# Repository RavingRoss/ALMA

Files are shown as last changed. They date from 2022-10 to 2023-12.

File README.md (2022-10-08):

# ALMA
The Advanced LASER Mining Array (ALMA) is a theoretical model of a Fiber LASER capable of mining ice water in space. This is being designed in the Engineering Physics Propulsion Lab at Embry Riddle Aeronautical University in Daytona Beach, FL. 

 A few examples that ALMA could mine are ice on the moon, C-type asteroids, comets, and other planetary bodies. There will be a downsized model of the LASER to help derive constants for the equations in the simulations and also for a proof-of-design. We are hoping the outcome will prove that you can use a FBL to mine ice water efficiently, with low energy and high output, in the vacuum of space. 
 
 The simulations will be based on the environment, meaning we can test the FBL in a vacuum, or on Venus. Decisions are still being made on what language and program to use for the simulations.

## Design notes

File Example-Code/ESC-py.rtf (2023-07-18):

# This program will let you test your ESC and brushless motor.

# Make sure your battery is not connected if you are going to calibrate it at first.

# Since you are testing your motor, I hope you don't have your propeller attached to it otherwise you are in trouble my friend...?

# This program is made by AGT @instructable.com. DO NOT REPUBLISH THIS PROGRAM... actually the program itself is harmful pssst Its not, its safe.

import os #importing os library so as to communicate with the system
import time #importing time library to make Rpi wait because its too impatient
os.system ("sudo pigpiod") #Launching GPIO library
time.sleep(1) # As i said it is too impatient and so if this delay is removed you will get an error
import pigpio #importing GPIO library

ESC=4 #Connect the ESC in this GPIO pin

pi = pigpio.pi();
pi.set_servo_pulsewidth(ESC, 0)

max_value = 2000 #change this if your ESC's max value is different or leave it be
min_value = 700 #change this if your ESC's min value is different or leave it be
print "For first time launch, select calibrate"
print "Type the exact word for the function you want"
print "calibrate OR manual OR control OR arm OR stop"

def manual_drive(): #You will use this function to program your ESC if required
print "You have selected manual option so give a value between 0 and you max value"
while True:
inp = raw_input()
if inp == "stop":
stop()
break
elif inp == "control":
control()
break
elif inp == "arm":
arm()
break
else:
pi.set_servo_pulsewidth(ESC,inp)

def calibrate(): #This is the auto calibration procedure of a normal ESC
pi.set_servo_pulsewidth(ESC, 0)
print("Disconnect the battery and press Enter")
inp = raw_input()
if inp == '':
pi.set_servo_pulsewidth(ESC, max_value)
print("Connect the battery NOW.. you will here two beeps, then wait for a gradual falling tone then press Enter")
inp = raw_input()
if inp == '':
pi.set_servo_pulsewidth(ESC, min_value)
print "Wierd eh! Special tone"
time.sleep(7)
print "Wait for it ...."
time.sleep (5)
print "Im working on it, DONT WORRY JUST WAIT....."
pi.set_servo_pulsewidth(ESC, 0)
time.sleep(2)
print "Arming ESC now..."
pi.set_servo_pulsewidth(ESC, min_value)
time.sleep(1)
print "See.... uhhhhh"
control() # You can change this to any other function you want

def control():
print "I'm Starting the motor, I hope its calibrated and armed, if not restart by giving 'x'"
time.sleep(1)
speed = 1500 # change your speed if you want to.... it should be between 700 - 2000
print "Controls - a to decrease speed & d to increase speed OR q to decrease a lot of speed & e to increase a lot of speed"
while True:
pi.set_servo_pulsewidth(ESC, speed)
inp = raw_input()

if inp == "q":
speed -= 100 # decrementing the speed like hell
print "speed = %d" % speed
elif inp == "e":
speed += 100 # incrementing the speed like hell
print "speed = %d" % speed
elif inp == "d":
speed += 10 # incrementing the speed
print "speed = %d" % speed
elif inp == "a":
speed -= 10 # decrementing the speed
print "speed = %d" % speed
elif inp == "stop":
stop() #going for the stop function
break
elif inp == "manual":
manual_drive()
break
elif inp == "arm":
arm()
break
else:
print "WHAT DID I SAID!! Press a,q,d or e"

def arm(): #This is the arming procedure of an ESC
print "Connect the battery and press Enter"
inp = raw_input()
if inp == '':
pi.set_servo_pulsewidth(ESC, 0)
time.sleep(1)
pi.set_servo_pulsewidth(ESC, max_value)
time.sleep(1)
pi.set_servo_pulsewidth(ESC, min_value)
time.sleep(1)
control()

def stop(): #This will stop every action your Pi is performing for ESC ofcourse.
pi.set_servo_pulsewidth(ESC, 0)
pi.stop()

#This is the start of the program actually, to start the function it needs to be initialized before calling... stupid python.

inp = raw_input()
if inp == "manual":
manual_drive()
elif inp == "calibrate":
calibrate()
elif inp == "arm":
arm()
elif inp == "control":
control()
elif inp == "stop":
stop()
else :
print "Thank You for not following the things I'm saying... now you gotta restart the program STUPID!!"

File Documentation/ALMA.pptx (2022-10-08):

## Advanced Laser mining array (alma)

Fiber Laser (FBL) using Ytterbium (Yb) doped fiber cable

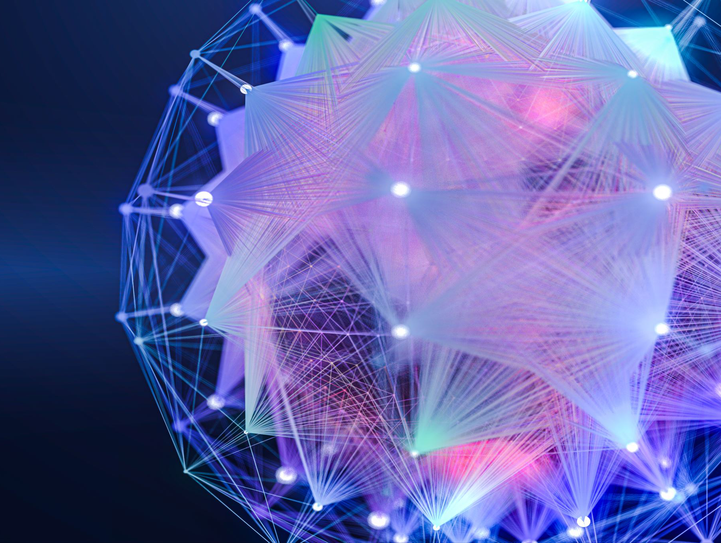
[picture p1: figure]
Purple patterned lights

Jacob R. Romeo

## Purpose and Plan for ALMA

- Main purpose will be to prove that the FBL could mine ice on the moon and NEOs.
- This involves making a downsized, low powered model to confirm the design.
- After, run Mathematical Models to know what we need to make the scaled version.
- Possibly getting funding for an up-scaled version.

## Design

- The Fiber Laser is pumped with a diode (976nm).
- The diode is coupled to the fiber cable.
- The doped, Yb core of the fiber cable uses stimulated emission to amplify the output.

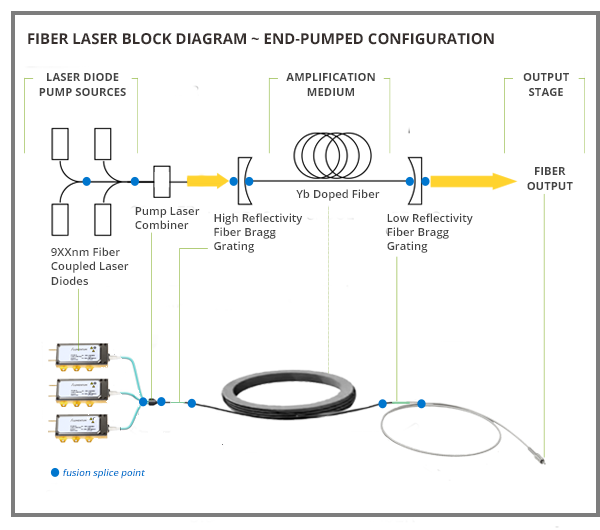
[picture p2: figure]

## Drilling Technique

- Different techniques are used for different applications.
- For our purposes, we want a large area with high energy impulses.
- Possibly using more than one output fiber to get a larger area of effect.

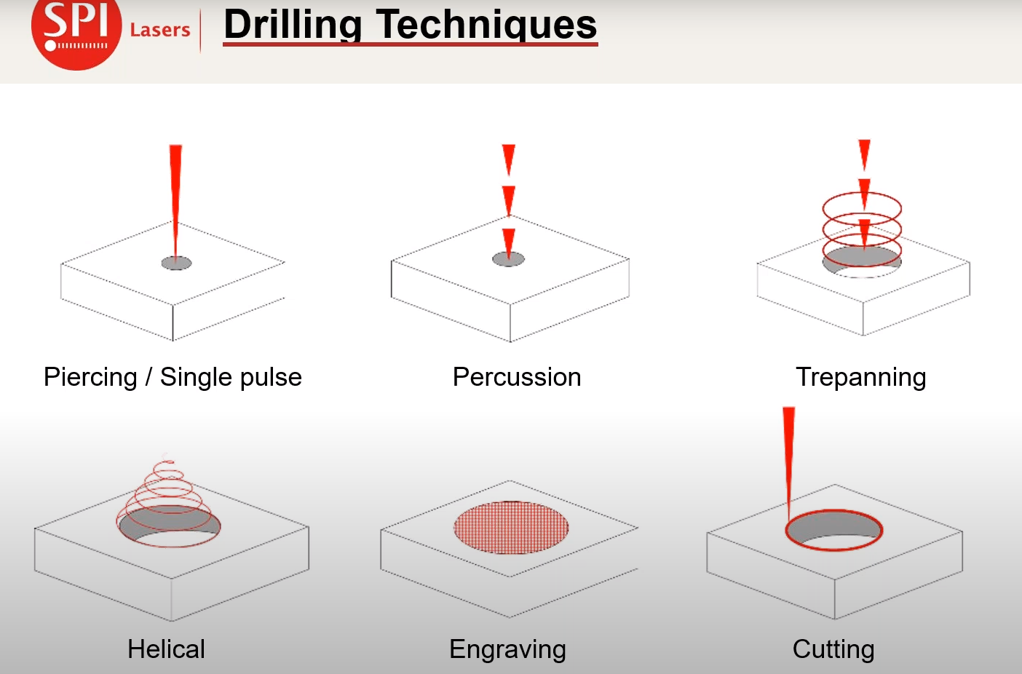
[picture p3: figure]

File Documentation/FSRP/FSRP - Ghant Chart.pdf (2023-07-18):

TASKS | M 1 | M 2 | M 3 | M 4 | M 5 | M 6 | M 7 | M 8 | M 9 | M 10 | M 11 | M 12

Confirm design specifications for 976nm BTF Diode, control board, Yb doped fiber optic, mirrors, and FBG's, then order components for the FBL and appratus

Get the absorption spectrum of water ice using a spectrometer and thin sheet of ice

Assemble the apparatus with the Yb fiber cable, mirror, and grating and mount the FBL for power testing

If Lasing, test with different grating angles to see which wavelength has best absoprtion effect on the ice to confirm the absorption spectrum

Start simulations in python to calculate power needed for high powered FBL and simulate this in Ansys

Order neccessary FBG to make a condensed design
Couple the fiber optics instead of a free-space design to condense the apparatus and show a plug-n-play design

Test power with plug-n-play design and confirm absorption spectra Use spectra from experiments in sumlations to more accurately depict effects on water ice in a vacuum environment

Reach out for more opportunities with NASA for future research

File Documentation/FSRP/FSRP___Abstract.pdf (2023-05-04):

## Advanced LASER Mining Array (ALMA)

Principal Investigator: Dr. Vikas Sudesh

Student Team: Jacob Romeo, Joseph DeMartini,

and Paige Loverick

April 2023

## 1 Abstract

ALMA is a fiber-laser (FBL) apparatus that will show a technique to mine water ice in space.

The ALMA will use absorbance to its advantage to melt water ice at low power so that energy

consumption is not an issue in space. Water ice’s absorption coefficient peaks in the near-infrared

range, thus the FBL will have an output ranging from 1060nm-1100nm. The FBL is going to

have a source (coupled diode) of 976nm, which will be of low wattage at 1.2W, being pumped

through the Ytterbium doped fiber cable. This is going to be done by using a variety of fiber

Bragg gratings to polarize the output to a specific wavelength. The purpose of this process is to

experimentally derive the absorption coefficient of water ice by melting it and reading its spectra

from a spectrometer so that the extinction coefficient can be solved. The extinction coefficient is

then used to find the absorbance, solving for the Intensity of the beam. After this is done, python

will be used to numerically solve (using the coefficients found) the equations for the physics inside

the FBL, so that Ansys can simulate a high-powered laser in a space environment. The reason

for doing this is due to costs, thus the ALMA team will be submitting future proposals to NASA

for larger grants in the future. This project is an huge learning curve and amazing experience for

the students working on this, including the assembly of the apparatus, the physics and concepts,

simulations, and working under time constraints.

1

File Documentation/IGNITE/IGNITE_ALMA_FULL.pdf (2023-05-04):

# Proof of Design for the Advanced LASER Mining Array (ALMA)

Principal Investigator: Jacob Romeo Student Team: Joseph DeMartini, Phoebe Fleshman, and Nathan Honderick
Supervisor: Dr. Sergey V. Drakunov

January 28, 2023

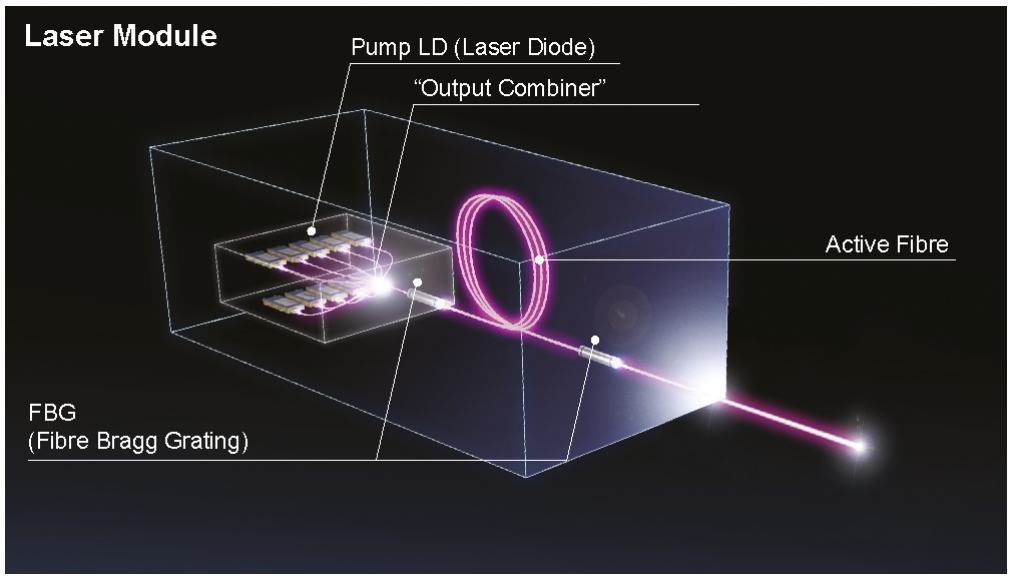
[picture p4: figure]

## Nomenclature

µ = 10⁻⁶

C − T ype = Carbonaceous chondrites

EP P L = Engineering Physics Propulsion Lab

Er = Erbium

F BG = Fiber Grating

F BL = Fiber LASER

K = Kelvin

LASER = Light Amplification by Stimulated Emission of Radiation

nd : Y AG = neodymium-doped:Yttrium Aluminium Garnet

NEO′ | s = Near earth objects

P P E = Personal Protective Equipment

SOP = Standardized Operating Procedure

Tm = Thulium

Y b = Ytterbium

## 1 Abstract

The goal of the ALMA project is to design and create an apparatus to test the ability of a FBL to mine water ice in space. This includes ice on the moon, NEO’s, and asteroids in the asteroid and Kuiper belt (which mainly consist of C-types and comets) [3]. ALMA is a down-sized version of the full lASER, being able to melt smaller chunks of ice. The reason for using a FBL versus a nd:YAG or CO2 gas LASER is to make use of the efficiency and accessibility of the FBL. The FBL is a more cost effective, and energy efficient laser, while also more compact than its counterparts [5]. The simpler design, allows it to be both reliable and maintenance-free during use [1]. Most high powered FBL’s have a recorded 30% - 50% power efficiency, much greater than other options [4]. Because of this the FBL was found to be the best option.
The basic design of a FBL utilizes: coupled diodes, a combiner, a Yb doped fiber cable, FBG (one of higher polarization on the input and another of low polarization on the output), and a FBG to protect the inside of the cable (Fig. 1 ). Due to the fact this project is researching means of mining in space, where the resting temperature is approximately 2.7K, there would be no use for cooling. More likely a means to find ways to shield the FBL from the space environment will need to be developed, because temperatures do not remain consistent once on the surface of the moon and other bodies in space. Because of this, the components will need to be changed based on the FBL based on its environment it is mining.
To complete the project and its goals, there will be a safety plan implemented as follows. The downsized model will have a system of precaution, including PPE, a safe and isolated environment for testing, and documentation with information disclosing safety measures.

## 2 Background

After Albert Einstein discovered the math that describes lasers in 1917, work stagnated until the 1950s with the first successful design in 1960. It wasn’t until 1963 when Elias Snitzer demonstrated a FBL [6]. This work was evolved to create lasers that are used to cut precious metals or in communication systems. In recent years the most common point of discussion is for mining, as it is the most rewarding possibility for FBLs to be used.
The function of a FBL works by using a diode coupled to a doped fiber optic cable, with amplification by stimulation. Some dopants for the amplification process are the elements Yb, Er, and Tm [6]. This process is called population inversion, defined as the redistribution of energy levels by collisional excitation of the electrons in the atom [7]. When electrons collide with a photon, from the pump source, it becomes energized and jumps to a higher energy level (Fig. 3 ). This process can be mathematically described by the elementary equation: E2 − E1 = ∆E = hf, where h is Plank’s Constant and f is the frequency of light. Once the electron goes back to the ground state and re-emits the photon, it gets reflected from the high reflective FBG, thus exciting more electrons and emitting more photons. From this quantum phenomena, a single photon can start a domino effect and amplify the input significantly and quickly.
The cladding of the fiber cable, surrounding the doped core, allows the light to have total internal reflection (Fig. 2 ) allowing minimal energy loss and scattering. This effect comes from Snell’s law: sin(θc) =

nclad
ncore

, where n is the refractive index. For this to work and there to be total internal reflection: nclad < ncore. There can be some scattering loss due to bending of the cable, which can be calculated and accounted for. The FBG on each end of the fiber filter the photons so that it can be reflected and energized to the correct wavelength (λ). For the current setup, ALMA will have λ ≈ 1070nm. The input grating has a larger reflectivity, thus no light can re-enter the diode and it is reflected to be amplified. Once the photon has reached the max wavelength (1070 nm), it is transmitted through the low reflectivity FBG.

## 3 Methodology

ALMA will be a down-scaled version of the theoretical FBL at about 1.2 Watts of peak output power, giving a pulse energy of .24µJ at a pulse width of 20µs. There will be a control board with the diode soldered on, giving us the ability to change the pulse-width parameters and input/output power. Within the lab, we plan on building a test cell made from 80/20 linear rails, the laser will be contained in the cell. Around this test cell will be a polarization screen, explained in section Safety Precautions. The apparatus will show mining techniques and collect spectra data from ice. This spectra data will be used when compiling the simulations, deriving the power needed to complete this task in different environments. The goal is to see how applicable this idea is with current technology. If not at all, the simulations can tell us why and what we need for it to come to fruition. It is also a lot more inconvenient and expensive to do tests with a higher powered FBL. Thus with the smaller version, ALMA is still able to experimentally derive the necessary processes that the simulations will be sourced from.
Currently, there is no precise value for the absorbance of ice, which is the lowest power requirement to melt ice. The basic definition of the absorbance, stated as the Beer-Lambert Law: An absorbance of 0 corresponds to a transmittance of 100% and an absorbance of 1 corresponds to 10% transmittance [11]. This comes from: A = αcl and α =

4πk
λ

, where A is absorbance, α is absorption coefficient, c is molar concentration, l is optical path length, k is extinction coefficient, and λ is wavelength. The absorption coefficient is defined: How far into a material light of a particular wavelength can penetrate before it is absorbed [12] and the extinction coefficient: How efficiently light is absorbed or reflected from a material [12]. Because of this, we will need to experimentally derive k and α to solve for A. This is important because without these values λ for the system is essentially an educated guess, which is what we are currently doing. Thus in the future, ALMA will need to incorporate different FBG, testing with different λs to derive the best absorbance value for the system.
Some other examples of why testing with different FBG will help ALMA’s progression include power output, beam quality, mining techniques, etc. Completing any of these experimentally will help the theoretical process and also make it more accurate for our goals.

| TASKS | START DATE | COMPLETION DATE
1 | IGNITE grant is rewarded | 07/2023 | -
2 | Order components for FBL and apparatus | 07/2023 | 08/2023
3 | Make apparatus to mount FBL | 08/2023 | 08/2023
4 | Start testing FBL | 08/2023 | 08/2023
5 | Research Symposium | Fall TBA | Fall TBA
6 | Collect spectra and mining data | 09/2023 | 11/2023
7 | Testing w/ more FBG(if enough $) | 11/2023 | 01/2024
8 | Repeat 6. with other FBG | 01/2024 | 02/2024
9 | Discovery Day | Spring TBA | Spring TBA
10 | Compile sim with spectra data | 03/2024 | 05/2024
11 | Publish research | 05/2024 | 05/2024
12 | Reach out for more opportunities | 05/2024 | 07/2024

## 4 Safety Precautions

The EPPL in room 123.1 of the COAS is a very secure environment to preform experiments. Storing ALL of ALMA’s equipment, including PPE, the apparatus, and experimental tools. There is also a test cage in which all of the experiments will be preformed along with a protective screen that blocks all light emission. The screen is present so that if light gets scattered or reflected it will not injure any researchers or damage sensitive equipment. The researchers working on ALMA will be wearing PPE at all times, including polarized goggles and latex gloves. In the test cage, there will be designated spot for NO crossing, where the beam would be active along with a sign outside the lab door signaling the use of a LASER. Money will also be allocated to buying a downsized test cell with the ability to install polarization features, in the case the screen cannot be purchased.

### 4.1 Storage’s SOP

Money for the FBL equipment will be allocated for secure, pelican crates for the equipment. It will be stored in a room behind a locked door, and will only be available to the PI once stored. Only 3 research interns and the supervisor have access to this door inside the lab once locked. The PPE will also be stored in pelican crates inside the test cage along with the equipment. The PPE includes polarized goggles, grounding cables, and protective gloves. Along with this, there will be NO jewelry of any kind when handling/experimenting with equipment.

### 4.2 Experiment’s SOP

The experiments will always be conducted inside the test cage, behind the locked door, inside the lab. There will be warning lights when the FBL is active and will be warning signs on the locked lab door and test cage at all times. Inside the test cage, there will be warning tape, at all times, where the beam would cross while active. The FBL will also have a switch to turn power on/off and a shutter on the output lens to block any light coming out of the FBL, on or off. Stated above, the test cage will have polarization tint so that if the beam gets reflected towards the cage, it will not be transmitted through the cage.

## 5 Significance

Space mining is one of the ”Big Talks” in fields of science and business alike. Once pioneered and efficient, mining in space will rid the need for ripping earth of its materials. If we continue to mine earth, we will eventually run out of resources within the millennia. Mining in space also gives humans the ability to complete space travel easier and generate new processes of wealth. This project introduces the concept of using a FBL to mine in space. From this project, the aerospace industry will have a new, optimized process of extracting water ice from space, allowing companies to make fuel from hydrogen or steam and have an oxygen supply. ALMA will also exponentially increase this team’s knowledge in areas of lab competency and safety, experimental processes of LASERs, physics of LASERs, and mathematics. Feeding this team the knowledge we need to be successful in each of our fields.

## 6 Communication Plans

The findings of ALMA will first and foremost be shared with Embry Riddle Aeronautical University. An accumulation of the findings, data, and simulations will also be shared to multiple journals in hopes of publication regarding the project. We will also apply for more grants and reach out to companies in hopes of partnership to further the research of ALMA.

## 7 Adequacy of Resources

All experiments will be conducted in the EPPL, room 123.1, in the College of Arts and Sciences at Embry Riddle Aeronautical University. There is sufficient space to include all measures for storage and operation, along with adequate tools and additional resources. The EPPL comes with 10 3D printers, including a 0.6 cubic meter printer, that are available for the ALMA team to use when needed. Dr. Sudesh, who has more than 20 years of experience in conducting experiments with FBLs, solid state LASERs, and optics, will be a mentor for the team. His knowledge and industry connections will help in many ways throughout this project. Also Dr. Drakunov, who is the founder of the lab, will provide an excellent source of knowledge when applying the results to the simulations.

## 8 Appendix


Figure 1: FBL design setup for amplification [7]

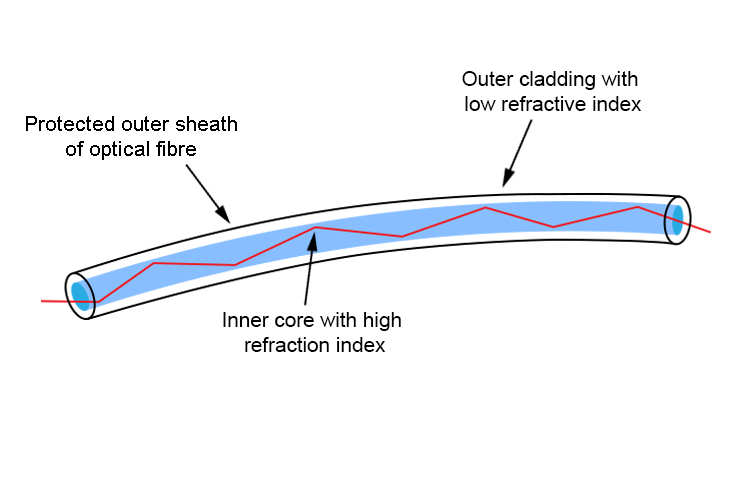
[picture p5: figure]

Figure 2: Example of total internal reflection in cable [8]

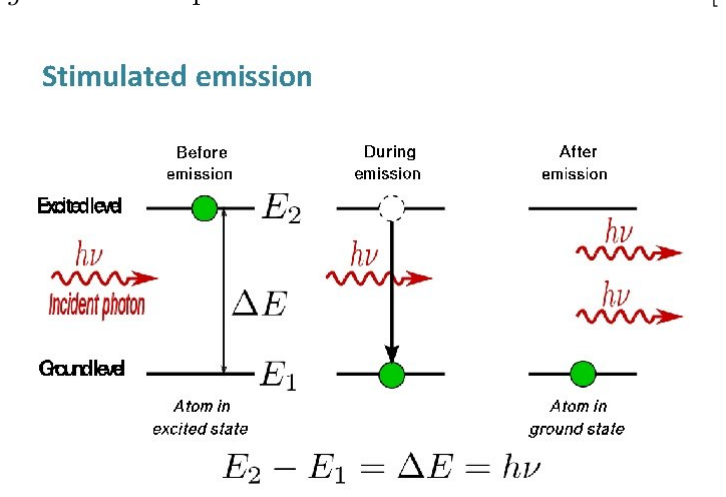
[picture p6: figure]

Figure 3: Population inversion cartoon example [9]

## 9 References

[1] Butterfly, B. (2022, March 15). Fiber Laser: 7 advantages and differences. FindLight Blog. Retrieved

October 3, 2022, from https://www.findlight.net/blog/2022/03/15/7-advantages-of-fiber-laser/

[2] Laserax. (2022, February 7). CO2 vs. Fiber Laser - which one should you buy? Laserax. Retrieved

October 3, 2022, from https://www.laserax.com/blog/co2-vs-fiber-lasers

[3] Lovett, R. A. (2021, January 8). From the vault: Icy asteroids? Cosmos. Retrieved October 3, 2022,

from https://cosmosmagazine.com/space/icy-asteroids/

[4] Photonic frontiers: High-efficiency optical pumping: ’going green ... (n.d.). Retrieved October 3, 2022,

from https://www.laserfocusworld.com/lasers-sources/article/16547048/photonic-frontiers-highefficiency-optical-

pumping-going-green-cranks-up-the-laser-power

[5] Laserax. (2021, September 23). Fiber Lasers: Everything You Need To Know. Laserax. Retrieved

October 3, 2022, from https://www.laserax.com/blog/fiber-laser#:˜:

text=1963%20%E2%80%93%20The%20first%20fiber%20laser,is%20demonstrated%20

(Elias%20Snitzer).

[6] What are rare-earth doped fibers? Fosco Connect. (n.d.). Retrieved October 3, 2022, from

https://www.fiberoptics4sale.com/blogs/archive-posts/95044294-what-are-rare-earth-doped-fibers

[7] Fiber Laser Basics and design principles. Fiber Laser Basics and Design Principles (with VIDEOS).

(n.d.). Retrieved October 3, 2022, from https://www.laserlabsource.com/Solid-State-Lasers/Solid-State-

Lasers/fiber-laser-basics-and-design-principles

[8] Total Internal Reflection. Total internal reflection experiments and optical fibres. (n.d.). Retrieved Oc-

tober 3, 2022, from https://mammothmemory.net/physics/refraction/total-internal-reflection-experiments-

and-optical-fibres/total-internal-reflection-experiments-and-optical-fibres.html

[9] Laser light amplification by stimulated emission of radiation. SlideToDoc.com.(n.d.).Retrieved Octo-

ber 3, 2022, from https://slidetodoc.com/laser-light-amplification-by-stimulated-emission-of-radiation-5/

[10] Sharp, T., amp; Urrutia, D. E. (2022, February 28). What is the temperature on the Moon?

Space.com. Retrieved January 31, 2023, from https://www.space.com/18175-moon-temperature.html

[11] Granite, S. by. (2023, February 14). Beer Lambert law: Transmittance amp; Absorbance. Edinburgh

Instruments. Retrieved February 24, 2023, from https://www.edinst.com/blog/the-beer-lambert-law/

[12] Absorption coefficient. PVEducation. (n.d.). Retrieved February 24, 2023, from

https://www.pveducation.org/pvcdrom/pn-junctions/absorption-coefficient

## 10 Student Group Resume

Jacob Romeo: A second semester junior in Astronomy and Astrophysics with research experience in

applied and theoretical physics, astronomy, electrical and software engineering, and control theory. Over 4

years of experience with electronics (PCB development) and coding in python. Experienced using Fusion360

CAD software, C++ and java, and development with raspberry-Pi’s and Arduino’s.

Phoebe Fleshman: A second semester junior in Engineering Physics with a focus on spacecraft systems.

Roughly 2 years of technical experience designing and building robots. Along with roughly 2 years of budget

creation and management . Experienced using Autodesk Inventor Pro, MatLab, and CNC mills.

Joseph DeMartini: A third year Engineering Physics student with professional experience in software

development and simulation. 5+ years of experience in Java, C#, and Unity3D development with an

understanding of advanced software development practices. Experience in applying numerical methods and

modern physics concepts to create high fidelity 3D physics simulations in optics, orbital mechanics, and

electromagnetism.

Nathan Honderick: A second semester freshman in Aerospace Engineering, specializing in Astronau-

tics. Experienced using Matlab, Onshape, Inventor, and Catia CAD software. Currently working on a

CubeSat, a laser mining array, a hybrid rocket engine, and developing a patent for an eco-friendly product

crafted from up-cycled beach plastic.

## 11 Detailed Budget

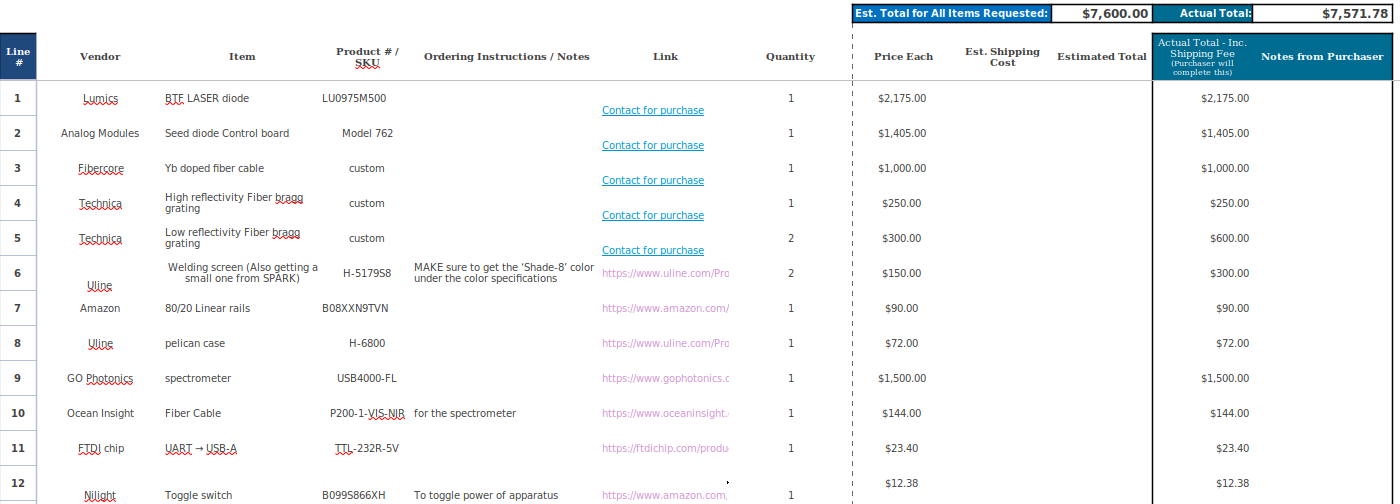
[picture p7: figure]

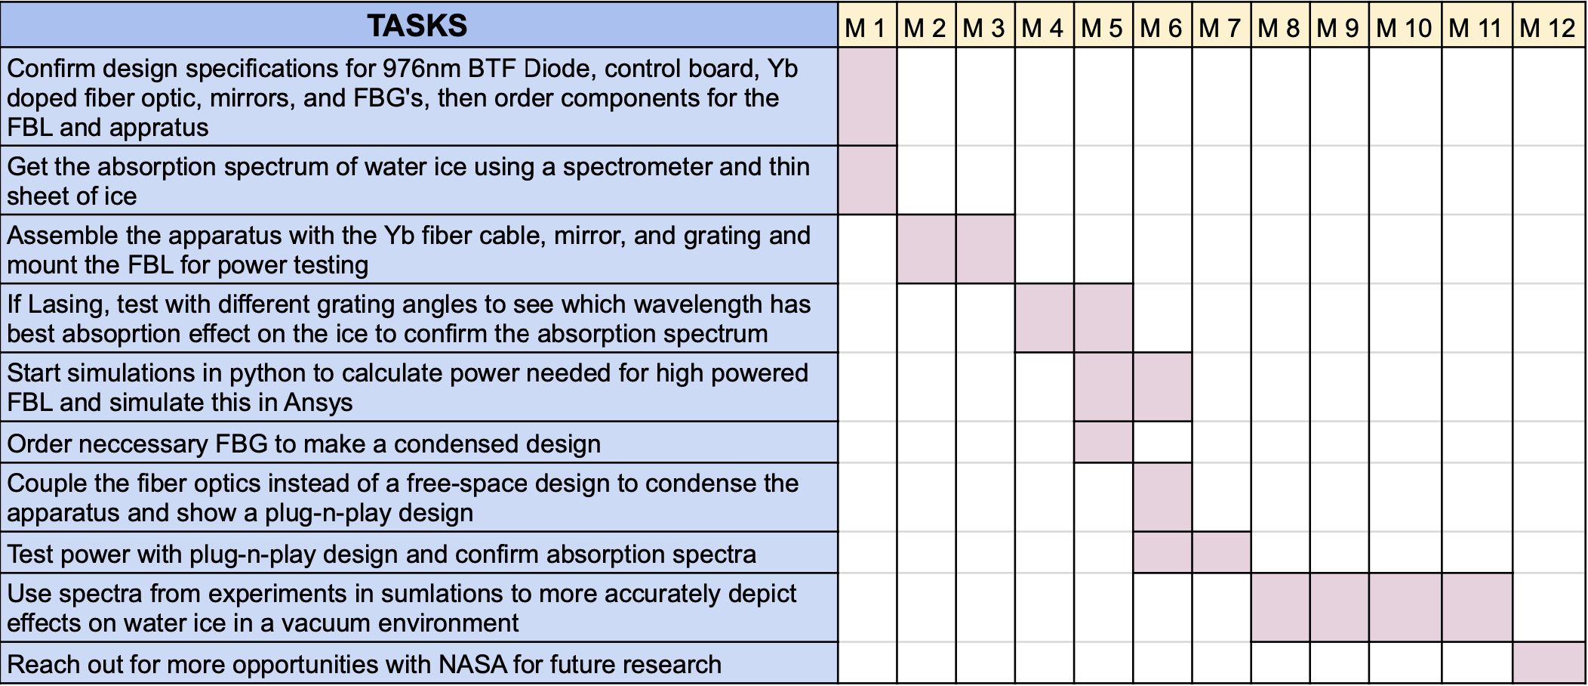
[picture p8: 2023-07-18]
Documentation/FSRP/Screenshot 2023-05-22 at 9.54.50 AM.png

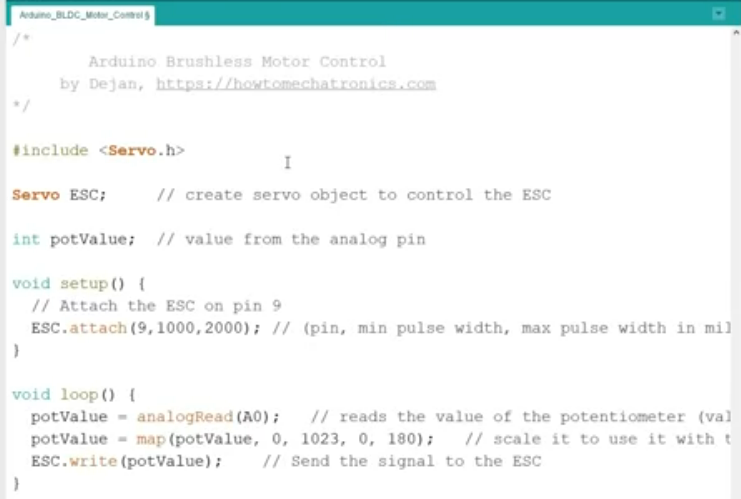
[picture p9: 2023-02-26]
Documentation/BLDC-ESC-Control.png

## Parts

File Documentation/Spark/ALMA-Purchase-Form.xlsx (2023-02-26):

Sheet: Instructions
Please click here to review the OUR Purchasing Guidelines prior to completing this form.
Purchase Request Form: • Used to request the purchase of all supplies/materials as needed. • Group all items by vendor. • Purchase from Amazon whenever possible. • Include any special instructions/details. • Include additional info for electronic and hazardous items in tabs below (required). • Provide direct links to exact item requested. • Provide shipping estimates. • Provide item ID #. • Provide lab/building address for shipment in email.
Electronic, computer & software purchases: • IT APPROVAL REQUIRED. • Provide a brief description of what the item(s) will be used for on the "Electronic Items" tab below. • OUR will obtain IT approval on your behalf. • Includes but not limited to: external hard drives, motherboards, Raspberry Pi, cameras, laptops, printers, etc.
Hazardous, chemical & gas purchases: • EH&S Review and Acceptance REQUIRED before purchasing. • You and your Faculty Mentor are responsible for obtaining a review and acceptance of your comprehensive SOP by the University’s Environmental Health & Safety Office prior to submitting Purchase Requests for hazardous, chemical, or gas purchases. • Complete the “Chemical & Compressed Gas Purchase” form linked in the "Hazardous & Chemicals" Tab below. • Once review is completed by EH&S, submit the acceptance with your Purchase Request Form to the OUR Business Manager and complete "Hazardous & Chemicals" Tab below.
Single Purchases $3,000 or more: • Due to the high expense, a Purchase Requisition must be submitted to purchase the item. • You must provide to the Business Manager along with your completed Purchase Request Form an itemized quote from the vendor and a copy of the vendor’s W-9 Form. • Single Purchases $5,000 or more are considered Capital Requests and require additional paperwork and approvals. • Please plan to purchase items of this nature as soon as possible as it often takes longer to process and receive the item.

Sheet: Purchase Request
 | Student Name: | Jacob R. Romeo |  | Project Title: | Advanced LASER Mining Array |  |  | Type of Funding (Spark, Ignite, Student Internal, SURF): |  | Spark
 | SHIP TO: (Faculty / Lab Director Name) | Engineering Physics Propulsion lab |  | Lab / Building Name and Building # : | COAS |  |  |  | Room # : | 123.1
 | Group items by vendor and include all relevant information needed for ordering. Email a copy of this to Liz Payne: paynee6@erau.edu.
 | ***Additional info MUST be provided on tabs below for ALL electronic, computer and hazardous/chemical items.***
 |  |  |  |  |  |  | Est. Total for All Items Requested: |  | $998.28 | Actual Total: | $998.28
Line # | Vendor | Item | Product # / SKU | Ordering Instructions / Notes | Link | Quantity | Price Each | Est. Shipping Cost | Estimated Total | Actual Total - Inc. Shipping Fee (Purchaser will complete this) | Notes from Purchaser
1 | Thorlabs | Round Wedge Prism 2* | PS810-C |  | https://www.thorlabs.com/thorproduct.cfm?partnumber=PS810-C | 2 | $54.16 |  | $108.32 | $108.32
2 | Thorlabs | Round Wedge Prism 4* | PS811-C |  | https://www.thorlabs.com/thorproduct.cfm?partnumber=PS811-C | 2 | $54.16 |  | $108.32 | $108.32
3 | Thorlabs | Round Wedge Prism 6* | PS812-C |  | https://www.thorlabs.com/thorproduct.cfm?partnumber=PS812-C | 2 | $54.16 |  | $108.32 | $108.32
4 | Flash Hobby | BLDC motors | B07545RQ62 |  | https://www.amazon.com/DYS-2200KV-Brushless-Multirotor-Quadcopter/dp/B07545RQ62 | 4 | $16.58 |  | $66.32 | $66.32
5 | Supulse | Electric Speed Controller | B071GRSFBD |  | https://www.amazon.com/RC-Brushless-Electric-Controller-bullet/dp/B071GRSFBD | 4 | $16.99 |  | $67.96 | $67.96
6 | Overture | 3D filament | N/A |  | https://www.amazon.com/OVERTURE-Filament-Printer-Dimensional-Accuracy/dp/B089S2QDHD | 1 | $20.00 |  | $20.00 | $20.00
7 | Zeee | 2 3s LiPo Batt | B07Y67MPKW |  | https://www.amazon.com/Zeee-Graphene-Quadcopter-Helicopter-Airplane/dp/B07Y67MPKW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 | 2 | $45.99 |  | $91.98 | $91.98
8 | Supulse | 4pcs LiPo Battery Case | FBB125x4-02 |  | https://www.amazon.com/Battery-Fireproof-Explosion-Proof-Storage/dp/B078Y723Z3?hvadid=459723993320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 | 1 | $14.99 |  | $14.99 | $14.99
9 | Civil Laser | 680nm 10mW Red laser module | Product 64/83:No Part number | HAVE to specify DOT shape, not line or crosshair | https://www.civillaser.com/index.php?main_page=product_info&products_id=1276 | 1 | $94.00 |  | $94.00 | $94.00
10 | AtomStack | LASER Protective Eye glasses | AtomOD5 |  | https://www.atomstack.net/products/atomstack-od5-laser-protective-glasses?currency=USD&variant=41033735405749 | 4 | $39.99 |  | $159.96 | $159.96
11 | Uline | Welding Screen | H-5179S8 | MAKE sure to get the ‘Shade-8’ color under the color specifications | https://www.uline.com/Product/Detail/H-5179S8/Welding/Welding-Screen-6-x-8-Shade-8 | 1 | $150.00 |  | $150.00 | $150.00
12 | Grainger | Safety sign | 451R27 |  | https://www.grainger.com/product/451R27?gucid=N:N:PS:Paid:GGL:CSM-2295:4P7A1P:20501231&gclsrc=aw.ds | 1 | $8.11 |  | $8.11 | $8.11
13 |  |  |  |  |  |  |  |  |  | $0.00
14 |  |  |  |  |  |  |  |  |  | $0.00
15 |  |  |  |  |  |  |  |  | $0.00 | $0.00
16 |  |  |  |  |  |  |  |  | $0.00 | $0.00
17 |  |  |  |  |  |  |  |  | $0.00 | $0.00
18 |  |  |  |  |  |  |  |  | $0.00 | $0.00
19 |  |  |  |  |  |  |  |  | $0.00 | $0.00
20 |  |  |  |  |  |  |  |  | $0.00 | $0.00
21 |  |  |  |  |  |  |  |  | $0.00 | $0.00
22 |  |  |  |  |  |  |  |  | $0.00 | $0.00
23 |  |  |  |  |  |  |  |  | $0.00 | $0.00
24 |  |  |  |  |  |  |  |  | $0.00 | $0.00
25 |  |  |  |  |  |  |  |  | $0.00 | $0.00
26 |  |  |  |  |  |  |  |  | $0.00 | $0.00
27 |  |  |  |  |  |  |  |  | $0.00 | $0.00
28 |  |  |  |  |  |  |  |  | $0.00 | $0.00
29 |  |  |  |  |  |  |  |  | $0.00 | $0.00
30 |  |  |  |  |  |  |  |  | $0.00 | $0.00
31 |  |  |  |  |  |  |  |  | $0.00 | $0.00
32 |  |  |  |  |  |  |  |  | $0.00 | $0.00
33 |  |  |  |  |  |  |  |  | $0.00 | $0.00
34 |  |  |  |  |  |  |  |  | $0.00 | $0.00
35 |  |  |  |  |  |  |  |  | $0.00 | $0.00
36 |  |  |  |  |  |  |  |  | $0.00 | $0.00
37 |  |  |  |  |  |  |  |  | $0.00 | $0.00
38 |  |  |  |  |  |  |  |  | $0.00 | $0.00
39 |  |  |  |  |  |  |  |  | $0.00 | $0.00
40 |  |  |  |  |  |  |  |  | $0.00 | $0.00
41 |  |  |  |  |  |  |  |  | $0.00 | $0.00
42 |  |  |  |  |  |  |  |  | $0.00 | $0.00
43 |  |  |  |  |  |  |  |  | $0.00 | $0.00
44 |  |  |  |  |  |  |  |  | $0.00 | $0.00
45 |  |  |  |  |  |  |  |  | $0.00 | $0.00
46 |  |  |  |  |  |  |  |  | $0.00 | $0.00
47 |  |  |  |  |  |  |  |  | $0.00 | $0.00
48 |  |  |  |  |  |  |  |  | $0.00 | $0.00
49 |  |  |  |  |  |  |  |  | $0.00 | $0.00
50 |  |  |  |  |  |  |  |  | $0.00 | $0.00
51 |  |  |  |  |  |  |  |  | $0.00 | $0.00
52 |  |  |  |  |  |  |  |  | $0.00 | $0.00
53 |  |  |  |  |  |  |  |  | $0.00 | $0.00
54 |  |  |  |  |  |  |  |  | $0.00 | $0.00
55 |  |  |  |  |  |  |  |  | $0.00 | $0.00
56 |  |  |  |  |  |  |  |  | $0.00 | $0.00
57 |  |  |  |  |  |  |  |  | $0.00 | $0.00
58 |  |  |  |  |  |  |  |  | $0.00 | $0.00
59 |  |  |  |  |  |  |  |  | $0.00 | $0.00
60 |  |  |  |  |  |  |  |  | $0.00 | $0.00
61 |  |  |  |  |  |  |  |  | $0.00 | $0.00
62 |  |  |  |  |  |  |  |  | $0.00 | $0.00
63 |  |  |  |  |  |  |  |  | $0.00 | $0.00
64 |  |  |  |  |  |  |  |  | $0.00 | $0.00
65 |  |  |  |  |  |  |  |  | $0.00 | $0.00
66 |  |  |  |  |  |  |  |  | $0.00 | $0.00
67 |  |  |  |  |  |  |  |  | $0.00 | $0.00
68 |  |  |  |  |  |  |  |  | $0.00 | $0.00
69 |  |  |  |  |  |  |  |  | $0.00 | $0.00
70 |  |  |  |  |  |  |  |  | $0.00 | $0.00
71 |  |  |  |  |  |  |  |  | $0.00 | $0.00
72 |  |  |  |  |  |  |  |  | $0.00 | $0.00
73 |  |  |  |  |  |  |  |  | $0.00 | $0.00
74 |  |  |  |  |  |  |  |  | $0.00 | $0.00
75 |  |  |  |  |  |  |  |  | $0.00 | $0.00
76 |  |  |  |  |  |  |  |  | $0.00 | $0.00
77 |  |  |  |  |  |  |  |  | $0.00 | $0.00
78 |  |  |  |  |  |  |  |  | $0.00 | $0.00
79 |  |  |  |  |  |  |  |  | $0.00 | $0.00
80 |  |  |  |  |  |  |  |  | $0.00 | $0.00
81 |  |  |  |  |  |  |  |  | $0.00 | $0.00
82 |  |  |  |  |  |  |  |  | $0.00 | $0.00
83 |  |  |  |  |  |  |  |  | $0.00 | $0.00
84 |  |  |  |  |  |  |  |  | $0.00 | $0.00
85 |  |  |  |  |  |  |  |  | $0.00 | $0.00
86 |  |  |  |  |  |  |  |  | $0.00 | $0.00
87 |  |  |  |  |  |  |  |  | $0.00 | $0.00
88 |  |  |  |  |  |  |  |  | $0.00 | $0.00
89 |  |  |  |  |  |  |  |  | $0.00 | $0.00
90 |  |  |  |  |  |  |  |  | $0.00 | $0.00
91 |  |  |  |  |  |  |  |  | $0.00 | $0.00
92 |  |  |  |  |  |  |  |  | $0.00 | $0.00
93 |  |  |  |  |  |  |  |  | $0.00 | $0.00
94 |  |  |  |  |  |  |  |  | $0.00 | $0.00
95 |  |  |  |  |  |  |  |  | $0.00 | $0.00
96 |  |  |  |  |  |  |  |  | $0.00 | $0.00
97 |  |  |  |  |  |  |  |  | $0.00 | $0.00
98 |  |  |  |  |  |  |  |  | $0.00 | $0.00
99 |  |  |  |  |  |  |  |  | $0.00 | $0.00
100 |  |  |  |  |  |  |  |  | $0.00 | $0.00

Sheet: Electronic Items
All electronic, computer, and technology items must be approved by IT prior to purchasing. The info below is required so that we can obtain IT approval on your behalf.
Line # from Purchase Request Form | Justification (why is the item needed, where will it be used / stored, will it be connected to the University network, etc.)
4 | Needed to rotate the prisms to receive a helical pattern, will be stored in a secured lab in a personal cabinet, and does not have wifi capabilities.
5 | Needed to control the motors (#4), will be stored along with the motors inside protective bags (#8), and does not have wifi capabilities.
7 | Needed to power #5, will be stored in a separate cabinet in the same lab inside protective bags (#8), and does not have wifi capabilities.
9 | The LASER is needed to create the mining pattern, will be stored away from a power source with the motors inside the lab, and does not have wifi capabilities.

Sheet: Hazardous & Chemical Items
ALL hazardous and chemical items require review and acceptance by Environmental Health & Safety. You and your Faculty Mentor are required to obtain EH&S review and acceptance of a comprehensive SOP prior to requesting hazardous items.
Line # from Purchase Request Form | Link to Safety Data Sheet | Chemical & Compressed Gas Purchase Form submitted to EH&S for hazardous items? Select Yes or No (https://ernie.erau.edu/Departments/ehs/Pages/Forms.aspx) | SOP Reviewed and Accepted by EH&S? Select Yes or No

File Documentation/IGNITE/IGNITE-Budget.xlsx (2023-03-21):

 | Student Name: | Jacob R. Romeo |  | Project Title: | Advanced LASER Mining Array |  |  | Type of Funding (Spark, Ignite, Student Internal, SURF): |  | IGNITE
 | SHIP TO: (Faculty / Lab Director Name) | Engineering Physics Propulsion lab |  | Lab / Building Name and Building # : | COAS |  |  |  | Room # : | 123.1
 | Group items by vendor and include all relevant information needed for ordering. Email a copy of this to Liz Payne: paynee6@erau.edu.
 | ***Additional info MUST be provided on tabs below for ALL electronic, computer and hazardous/chemical items.***
 |  |  |  |  |  |  | Est. Total for All Items Requested: |  | $7600.00 | Actual Total: | $7571.78
Line # | Vendor | Item | Product # / SKU | Ordering Instructions / Notes | Link | Quantity | Price Each | Est. Shipping Cost | Estimated Total | Actual Total - Inc. Shipping Fee (Purchaser will complete this) | Notes from Purchaser
1 | Lumics | BTF LASER diode | LU0975M500 |  | Contact for purchase | 1 | $2175.00 |  |  | $2175.00
2 | Analog Modules | Seed diode Control board | Model 762 |  | Contact for purchase | 1 | $1405.00 |  |  | $1405.00
3 | Fibercore | Yb doped fiber cable | custom |  | Contact for purchase | 1 | $1000.00 |  |  | $1000.00
4 | Technica | High reflectivity Fiber bragg grating | custom |  | Contact for purchase | 1 | $250.00 |  |  | $250.00
5 | Technica | Low reflectivity Fiber bragg grating | custom |  | Contact for purchase | 2 | $300.00 |  |  | $600.00
6 | Uline | Welding screen (Also getting a small one from SPARK) | H-5179S8 | MAKE sure to get the ‘Shade-8’ color under the color specifications | https://www.uline.com/Product/Detail/H-5179S8/Welding/Welding-Screen-6-x-8-Shade-8 | 2 | $150.00 |  |  | $300.00
7 | Amazon | 80/20 Linear rails | B08XXN9TVN |  | https://www.amazon.com/dp/B08XXN9TVN/ref=syn_sd_onsite_desktop_0?ie=UTF8&pd_rd_plhdr=t&th=1 | 1 | $90.00 |  |  | $90.00
8 | Uline | pelican case | H-6800 |  | https://www.uline.com/Product/Detail/H-6800/Special-Use-Boxes/Pelican-1200-Equipment-Case?id=H-6800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 | 1 | $72.00 |  |  | $72.00
9 | GO Photonics | spectrometer | USB4000-FL |  | https://www.gophotonics.com/products/spectrometers/ocean-optics-inc/44-543-usb4000-fl | 1 | $1500.00 |  |  | $1500.00
10 | Ocean Insight | Fiber Cable | P200-1-VIS-NIR | for the spectrometer | https://www.oceaninsight.com/products/fibers-and-probes/fibers/patch-cords/p200-1-vis-nir/?qty=1 | 1 | $144.00 |  |  | $144.00
11 | FTDI chip | UART → USB-A | TTL-232R-5V |  | https://ftdichip.com/products/ttl-232r-5v/ | 1 | $23.40 |  |  | $23.40
12 | Nilight | Toggle switch | B099S866XH | To toggle power of apparatus | https://www.amazon.com/Nilight-90014E-Rocker-Toggle-Warranty/dp/B099S866XH?hvadid=362768105905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 | 1 | $12.38 |  |  | $12.38
13 |  |  |  |  |  |  |  |  |  | $0.00
14 |  |  |  |  |  |  |  |  |  | $0.00
15 | Gen Supplies | All equipment will be re-usable if not defected |  |  |  |  |  |  | $0.00 | $0.00
16 | Gen equipment | everything |  |  |  |  |  |  | $0.00 | $0.00
17 | Computer equip and soft | the control board comes with software needed |  |  |  |  |  |  | $0.00 | $0.00
18 |  |  |  |  |  |  |  |  | $0.00 | $0.00
19 |  |  |  |  |  |  |  |  | $0.00 | $0.00
20 |  |  |  |  |  |  |  |  | $0.00 | $0.00
21 |  |  |  |  |  |  |  |  | $0.00 | $0.00
22 |  |  |  |  |  |  |  |  | $0.00 | $0.00
23 |  |  |  |  |  |  |  |  | $0.00 | $0.00
24 |  |  |  |  |  |  |  |  | $0.00 | $0.00
25 |  |  |  |  |  |  |  |  | $0.00 | $0.00
26 |  |  |  |  |  |  |  |  | $0.00 | $0.00
27 |  |  |  |  |  |  |  |  | $0.00 | $0.00
28 |  |  |  |  |  |  |  |  | $0.00 | $0.00
29 |  |  |  |  |  |  |  |  | $0.00 | $0.00
30 |  |  |  |  |  |  |  |  | $0.00 | $0.00
31 |  |  |  |  |  |  |  |  | $0.00 | $0.00
32 |  |  |  |  |  |  |  |  | $0.00 | $0.00
33 |  |  |  |  |  |  |  |  | $0.00 | $0.00
34 |  |  |  |  |  |  |  |  | $0.00 | $0.00
35 |  |  |  |  |  |  |  |  | $0.00 | $0.00
36 |  |  |  |  |  |  |  |  | $0.00 | $0.00
37 |  |  |  |  |  |  |  |  | $0.00 | $0.00
38 |  |  |  |  |  |  |  |  | $0.00 | $0.00
39 |  |  |  |  |  |  |  |  | $0.00 | $0.00
40 |  |  |  |  |  |  |  |  | $0.00 | $0.00
41 |  |  |  |  |  |  |  |  | $0.00 | $0.00
42 |  |  |  |  |  |  |  |  | $0.00 | $0.00
43 |  |  |  |  |  |  |  |  | $0.00 | $0.00
44 |  |  |  |  |  |  |  |  | $0.00 | $0.00
45 |  |  |  |  |  |  |  |  | $0.00 | $0.00
46 |  |  |  |  |  |  |  |  | $0.00 | $0.00
47 |  |  |  |  |  |  |  |  | $0.00 | $0.00
48 |  |  |  |  |  |  |  |  | $0.00 | $0.00
49 |  |  |  |  |  |  |  |  | $0.00 | $0.00
50 |  |  |  |  |  |  |  |  | $0.00 | $0.00
51 |  |  |  |  |  |  |  |  | $0.00 | $0.00
52 |  |  |  |  |  |  |  |  | $0.00 | $0.00
53 |  |  |  |  |  |  |  |  | $0.00 | $0.00
54 |  |  |  |  |  |  |  |  | $0.00 | $0.00
55 |  |  |  |  |  |  |  |  | $0.00 | $0.00
56 |  |  |  |  |  |  |  |  | $0.00 | $0.00
57 |  |  |  |  |  |  |  |  | $0.00 | $0.00
58 |  |  |  |  |  |  |  |  | $0.00 | $0.00
59 |  |  |  |  |  |  |  |  | $0.00 | $0.00
60 |  |  |  |  |  |  |  |  | $0.00 | $0.00
61 |  |  |  |  |  |  |  |  | $0.00 | $0.00
62 |  |  |  |  |  |  |  |  | $0.00 | $0.00
63 |  |  |  |  |  |  |  |  | $0.00 | $0.00
64 |  |  |  |  |  |  |  |  | $0.00 | $0.00
65 |  |  |  |  |  |  |  |  | $0.00 | $0.00
66 |  |  |  |  |  |  |  |  | $0.00 | $0.00
67 |  |  |  |  |  |  |  |  | $0.00 | $0.00
68 |  |  |  |  |  |  |  |  | $0.00 | $0.00
69 |  |  |  |  |  |  |  |  | $0.00 | $0.00
70 |  |  |  |  |  |  |  |  | $0.00 | $0.00
71 |  |  |  |  |  |  |  |  | $0.00 | $0.00
72 |  |  |  |  |  |  |  |  | $0.00 | $0.00
73 |  |  |  |  |  |  |  |  | $0.00 | $0.00
74 |  |  |  |  |  |  |  |  | $0.00 | $0.00
75 |  |  |  |  |  |  |  |  | $0.00 | $0.00
76 |  |  |  |  |  |  |  |  | $0.00 | $0.00
77 |  |  |  |  |  |  |  |  | $0.00 | $0.00
78 |  |  |  |  |  |  |  |  | $0.00 | $0.00
79 |  |  |  |  |  |  |  |  | $0.00 | $0.00
80 |  |  |  |  |  |  |  |  | $0.00 | $0.00
81 |  |  |  |  |  |  |  |  | $0.00 | $0.00
82 |  |  |  |  |  |  |  |  | $0.00 | $0.00
83 |  |  |  |  |  |  |  |  | $0.00 | $0.00
84 |  |  |  |  |  |  |  |  | $0.00 | $0.00
85 |  |  |  |  |  |  |  |  | $0.00 | $0.00
86 |  |  |  |  |  |  |  |  | $0.00 | $0.00
87 |  |  |  |  |  |  |  |  | $0.00 | $0.00
88 |  |  |  |  |  |  |  |  | $0.00 | $0.00
89 |  |  |  |  |  |  |  |  | $0.00 | $0.00
90 |  |  |  |  |  |  |  |  | $0.00 | $0.00
91 |  |  |  |  |  |  |  |  | $0.00 | $0.00
92 |  |  |  |  |  |  |  |  | $0.00 | $0.00
93 |  |  |  |  |  |  |  |  | $0.00 | $0.00
94 |  |  |  |  |  |  |  |  | $0.00 | $0.00
95 |  |  |  |  |  |  |  |  | $0.00 | $0.00
96 |  |  |  |  |  |  |  |  | $0.00 | $0.00
97 |  |  |  |  |  |  |  |  | $0.00 | $0.00
98 |  |  |  |  |  |  |  |  | $0.00 | $0.00
99 |  |  |  |  |  |  |  |  | $0.00 | $0.00
100 |  |  |  |  |  |  |  |  | $0.00 | $0.00

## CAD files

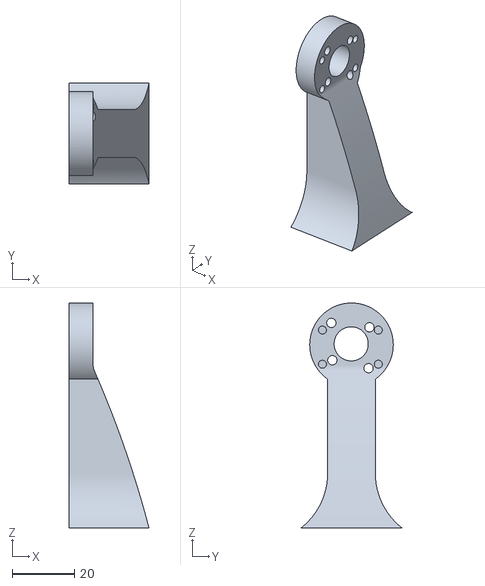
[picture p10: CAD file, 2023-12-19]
Prints/BLDC-Mount.stl
25.8 x 32.6 x 72.5

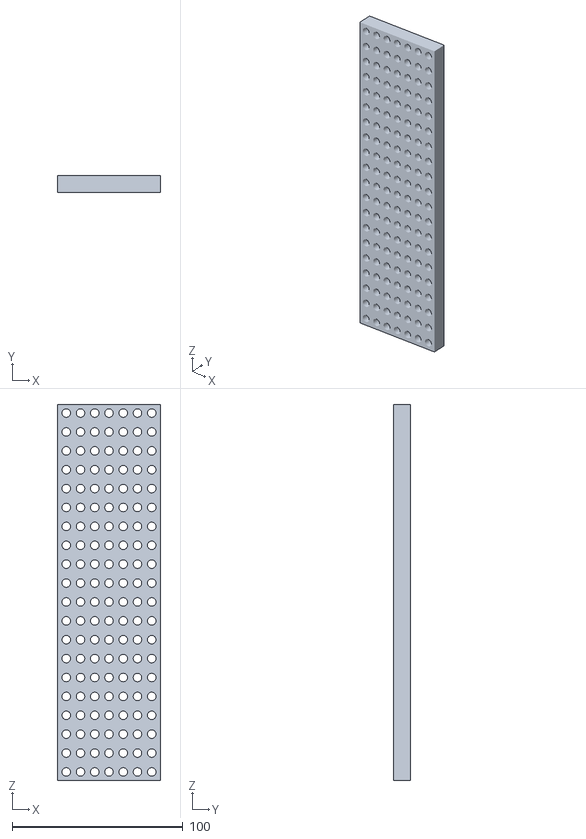
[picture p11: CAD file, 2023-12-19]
Prints/breadboard.stl
60.0 x 10.0 x 220.0

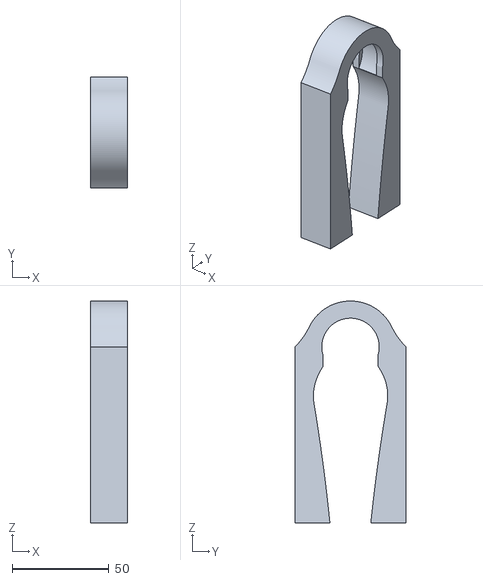
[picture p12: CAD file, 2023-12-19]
Prints/Wedge Stand - V5.stl
19.0 x 57.4 x 114.6

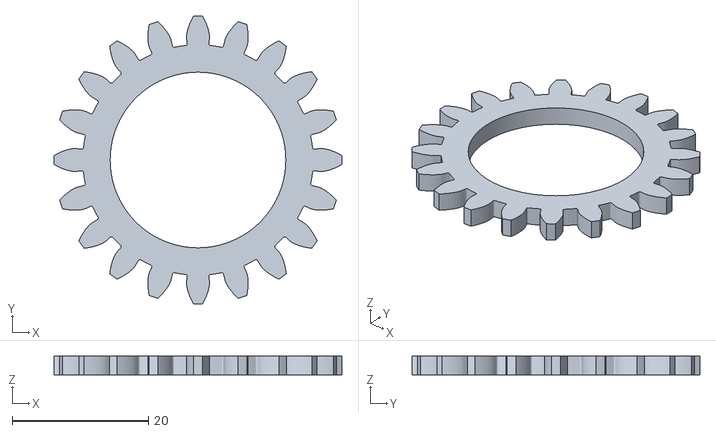
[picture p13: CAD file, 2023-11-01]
Prints/wedge-mount.stl
42.3 x 42.3 x 2.76

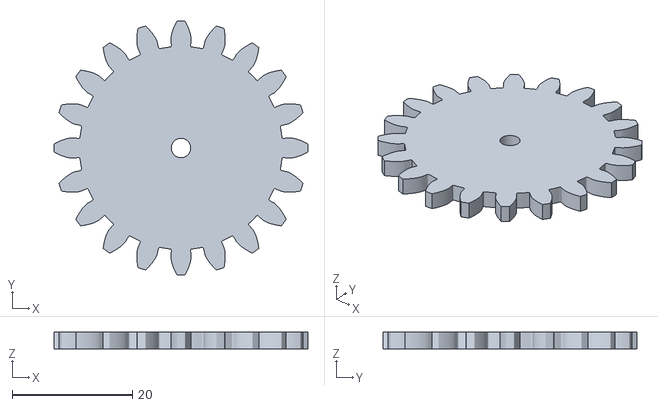
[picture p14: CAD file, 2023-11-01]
Prints/motor-gear.stl
42.3 x 42.3 x 2.76

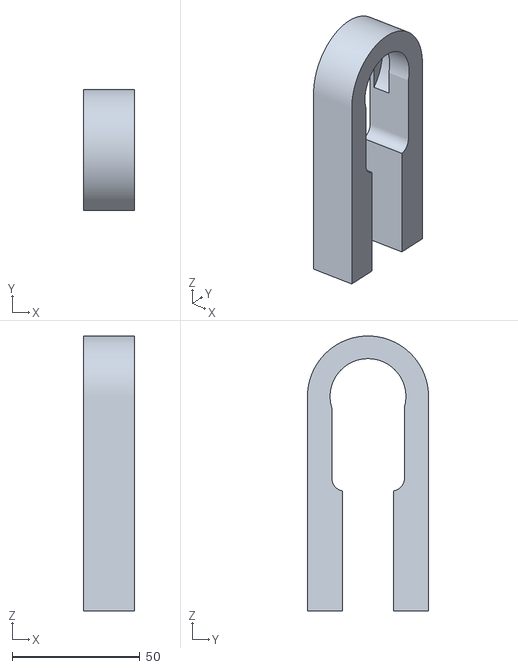
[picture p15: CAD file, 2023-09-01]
Prints/Wedge-Stand.stl
20.0 x 47.4 x 107.6

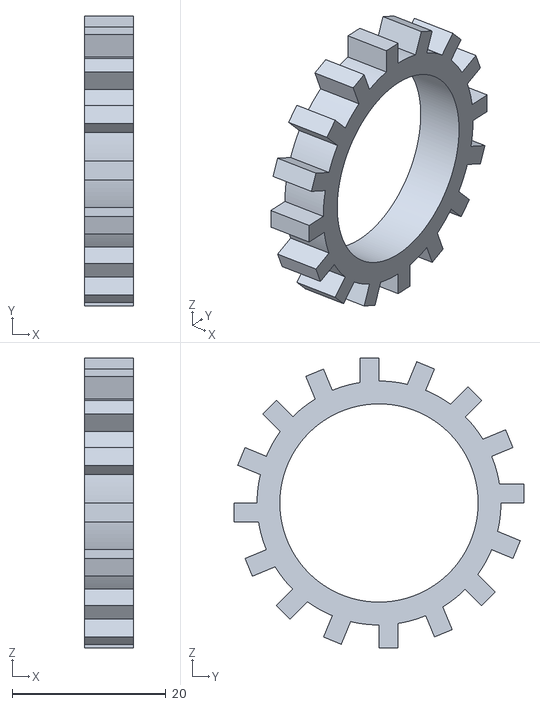
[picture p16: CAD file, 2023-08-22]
Prints/Wedge-Holder.stl
6.35 x 37.8 x 37.8

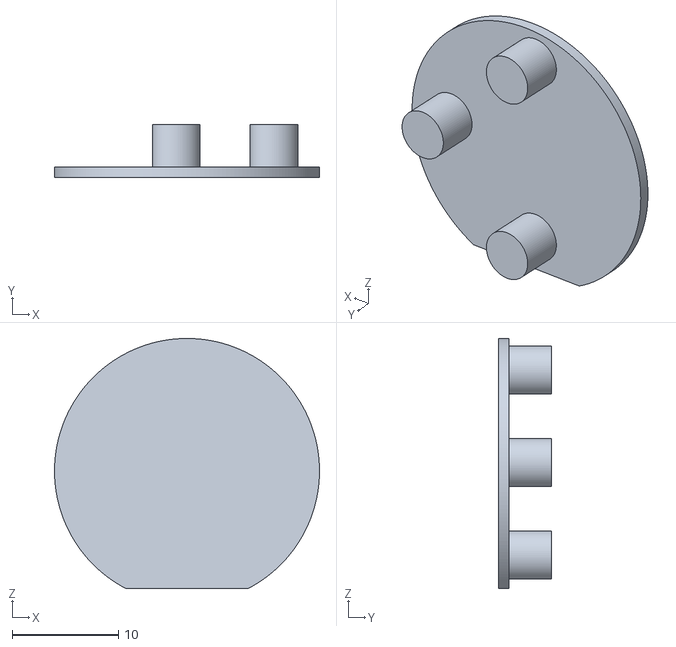
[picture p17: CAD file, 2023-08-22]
Prints/BLDC-Holes.stl
24.9 x 5.00 x 23.5

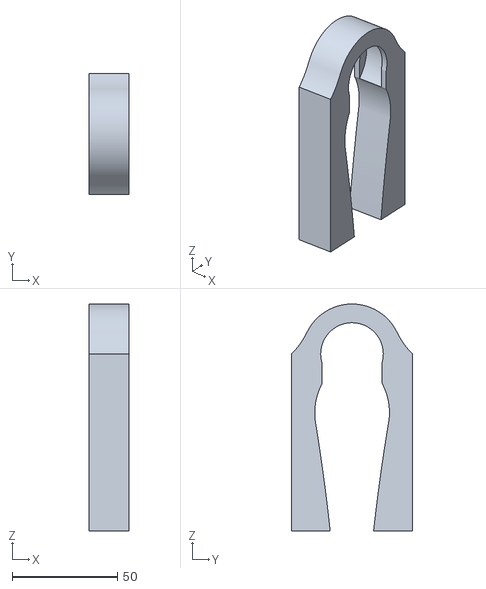
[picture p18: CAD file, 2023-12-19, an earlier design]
Prints/Wedge Stand - V4.stl
19.0 x 57.4 x 107.6

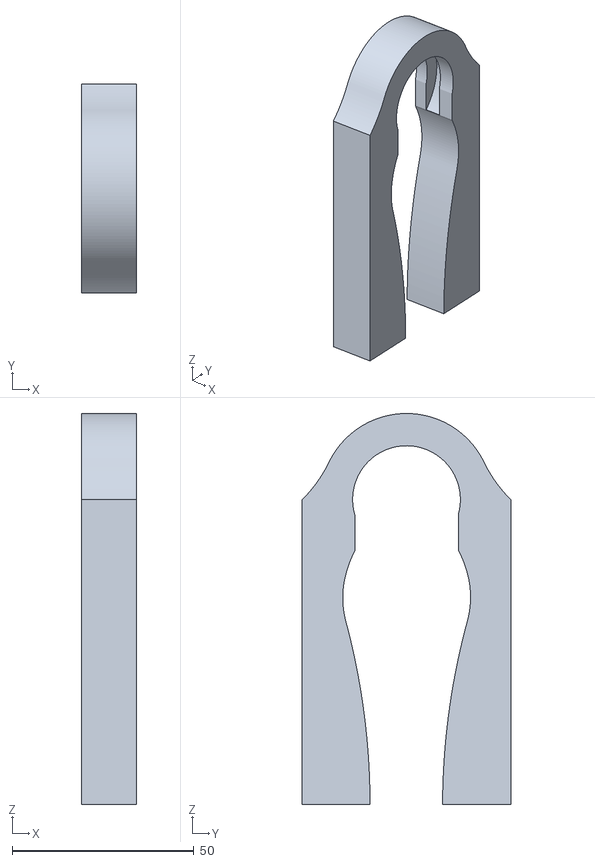
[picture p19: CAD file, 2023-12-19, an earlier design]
Prints/Wedge Stand - V3.stl
15.0 x 57.4 x 107.6

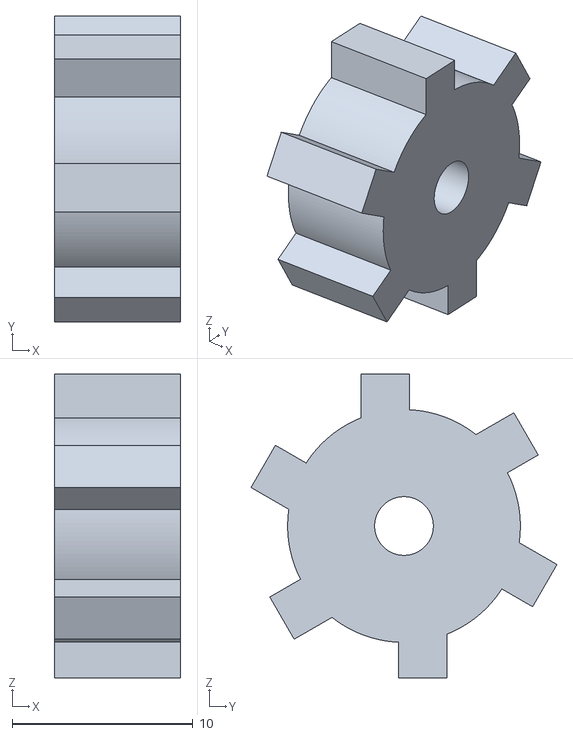
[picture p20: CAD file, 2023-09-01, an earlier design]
Prints/motor-gear-V2.stl
7.00 x 16.9 x 16.8

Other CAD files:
Prints/Wedge Stand.f3d
Prints/motor gear.f3d
Prints/motor gear.ipt
Prints/motor gear.stl
Prints/wedge holder.f3d
Prints/wedge holder.ipt
Prints/wedge holder.stl

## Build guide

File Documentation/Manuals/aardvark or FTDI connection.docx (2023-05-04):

I2C Communication requires Total Phase Aardvark I2C/SPI host adapter. J7 Pin 14 must be pulled low.

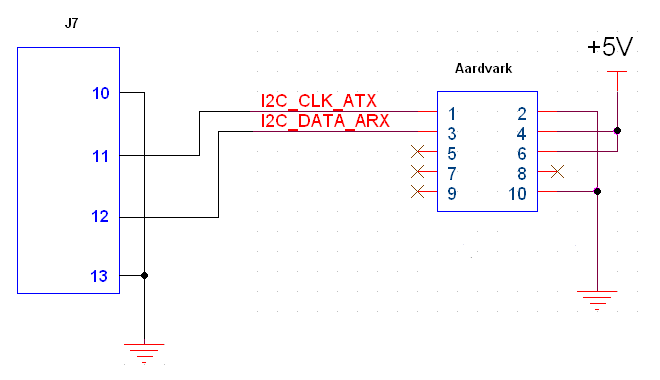
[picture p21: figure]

Asynchronous Serial communication requires an FTDI P/N TTL-232R-5V USB converter cable. J7 Pin 14 must be left high (open).

J7-10 to Pin 1 GND

J7-11 to Pin 5 RXD

J7-12 to Pin 4 TXD

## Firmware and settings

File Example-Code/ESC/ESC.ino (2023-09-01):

#include <Servo.h>
#define LED_PIN 8
byte servoPin = 9; // signal pin for the ESC.
byte potentiometerPin = A0; // analog input pin for the potentiometer.
Servo servo;

void setup() {

pinMode(LED_PIN, OUTPUT);

servo.attach(servoPin);
servo.writeMicroseconds(1500); // send "stop" signal to ESC. Also necessary to arm the ESC.

delay(7000); // delay to allow the ESC to recognize the stopped signal.
}

void loop() {

int potentiometerValue = analogRead(potentiometerPin);
int brightness = potentiometerValue / 4;
analogWrite(LED_PIN, brightness);

int potVal = analogRead(potentiometerPin); // read input from potentiometer.

int pwmVal = map(potVal,0, 1023, 1100, 1900); // maps potentiometer values to PWM value.

servo.writeMicroseconds(pwmVal); // Send signal to ESC.
}

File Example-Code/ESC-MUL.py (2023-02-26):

# Multi ESC Calibration for Drones
import os    
import time   
os.system ("sudo pigpiod") 
time.sleep(1) 
import pigpio 

ESC = 17  
ESC_2 = 18
ESC_3 = 27
ESC_4 = 22

Count_ESC = [ESC , ESC_2, ESC_3, ESC_4]
 

pi = pigpio.pi();

for E in Count_ESC:
    pi.set_servo_pulsewidth(E, 0) 

max_value = 2000 
min_value = 790  

    print("please disconnect battery.. then press kal")
                
def calibrate():   
    for E in Count_ESC: 
        pi.set_servo_pulsewidth(E, 0)
        time.sleep(1)
        pi.set_servo_pulsewidth(E, max_value)
    print("Connect battery.. then press Enter")
    inp = raw_input()
    if inp == '': 
        for E in Count_ESC:
            pi.set_servo_pulsewidth(E, min_value)   
        time.sleep(7)
        time.sleep (5)        
        for E in Count_ESC:
            pi.set_servo_pulsewidth(E, 0)           
        time.sleep(2) 
        print "Arming.."
        for E in Count_ESC:
            pi.set_servo_pulsewidth(E, min_value)
        time.sleep(1)
        control()
                   
             
def control(): 

    time.sleep(1)
    speed = min_value
    print "a : decrease speed & d : increase speed | q : decrease a lot & e : increase a lot"
    while True:
        for E in Count_ESC:
            pi.set_servo_pulsewidth(E, speed)
        inp = raw_input()
        
        if inp == "q":
            speed -= 100    
            print "speed = %d" % speed
        elif inp == "e":    
            speed += 100    
            print "speed = %d" % speed
        elif inp == "d":
            speed += 10     
            print "speed = %d" % speed
        elif inp == "a":
            speed -= 10     
            print "speed = %d" % speed
        elif inp == "stop":
            stop()          
            break
        else:
            print "Press a,q,d or e"
      
def stop(): 
    for E in Count_ESC:
        pi.set_servo_pulsewidth(E, 0)
    pi.stop()

  
inp = raw_input()

if inp == "kal":
    calibrate()

elif inp == "stop":
    stop()

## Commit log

2023-02-18 Spark Grant
    [ALMA-Purchase-Form.xlsx]
2023-03-21 modified: Documentation/IGNITE/IGNITE-Budget.xlsx modified: Documentation/IGNITE/IGNITE_ALMA.pdf deleted: Documentation/Nonlinear-FBL-Dynamics.pdf deleted: Documentation/Philanthropy/Grant_Proposal.p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
    [IGNITE-Budget.xlsx]
2023-09-01 fusion fIles uploaded
    [Wedge Stand.f3d, motor gear.f3d, wedge holder.f3d]
2023-12-19 updated recent results
    [BLDC-Mount.stl, Wedge Stand - V3.stl, Wedge Stand - V4.stl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]
